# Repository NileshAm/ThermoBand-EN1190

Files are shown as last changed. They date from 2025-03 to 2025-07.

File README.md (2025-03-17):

# ThermoBand-EN1190
This is for EN1190 Design Project module. This repository contains all the design files, code and other resourse we needed to devolop the ThrmoBand Product.
## Documantation
Docimentation folder contaoin all the document in this project.
1. Proposal
2. Badget calculations
3. Survey Data.

<hr/>

<span style="font-size:1.5em;">**More details about code is in [README.md](Code/README.md) file in the Code folder**</span>
<hr/>

<span style="font-size:1.5em;">**More details about design is in [README.md](Design\README.md) file in the design folder**</span>

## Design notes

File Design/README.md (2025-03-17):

# Design
## Overview
<span style="font-size:1.2em">This contains all the design specifications and design files of the product.</span>

* Break out board must be connected in a way that **wifi chip is facing the LED**, and USB terminal is on the free end.
    * ***Note : Make sure the ```Vin``` and ```GND``` pins line up with the 2 female header pins.***
* Vin must be supplied with 5V.
* All buttons as connected to ```GND``` on free end.(Except ```D0``` button).
* As RGB LED is a commom anode LED its common terminal is connected to Vin. When power through USB or other wise LED might not turn on as Vin would not be powered.

## Circuit
### Pin out
1. **D0 (GPIO16) :**  
    * Can be connected to either push button 3 for the reset depending on the requirement.

        1.1. **Button Mode :** Put the jumper to the top position. (*Only configurable as a pull down button.*)

        1.2. **Wake Mode :** Put the jumper tot the lower position.(*Then pin is connected to RST pin and can be used to wake the ESP from deep sleep.*)

2. **D1 (GPIO5) :**  
    * Connected to the middle push button.
    * Internally pulled up (to 3.3V) by code.

3. **D2 (GPIO4) :**  
    * Connected to the **DS18B20** temperature sensor.
    * There is a 3.9 kΩ resistor to 3.3V

4. **D3 (GPIO0) :** 
    * Connected to the middle push button.
    * Internally pulled up (to 3.3V) by code.
    * **Note : *As this pin is also connected to flash pin of ESP make sure not to push while booting up.***
5. **D4 (GPIO2) :**
    * Pin of the built in LED.
    * Connecting any thing might lead to built in LED not operating as intented.
6. **3V & GND :**
    * In this board there seem that these 2 pinsare not connected or mulfunctioning.
7. **D5 (GPIO14) :**
    * Connected to the **Red** pin of the RGB LED with a 220Ω resistor.
    * As the LED is a common anode LED, pin must be set to ```LOW``` to light the LED.
8. **D6 (GPIO12) :**
    * Connected to the **Blue** pin of the RGB LED with a 220Ω resistor.
    * As the LED is a common anode LED, pin must be set to ```LOW``` to light the LED.
9. **D7 (GPIO13) :**
    * Connected to the **Green** pin of the RGB LED with a 220Ω resistor.
    * As the LED is a common anode LED, pin must be set to ```LOW``` to light the LED.
10. **D8 (GPIO15) :**
    * As its a boot critical pin avoid connecting anything to this pin.
11. **RST Pin:**
    * Depending on jumper position either connected to ```D0``` or not connected at all. Refer ```D0``` pinout for more info.

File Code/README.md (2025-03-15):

# Code

## Overview
* <code>main/src/</code> folder contains all the library and header files needed to run the program.
    * Add put header files into its over folder and then put folder in the src file to compile the library at compilation time.
    * **Note**: If files would not be compiled of put anyway else and this behaviour can lead to compilation errors.
* <code>[main.ino](main/main.ino)</code> main file which is uploaded to the ESP.

## Be Aware
1. **Do not** change the codes marked as not to edit as it could break the WIFI programming. And might need to erase the memory and reupload the code from scratch.

## Setting up WIFI Programmer on ESP
1. Reset and clear the ESP flash memory by running
<code>python -m esptool --chip esp8266 erase_flash
</code>.(**Hold down the flash button of the ESP while the command is running.**) [More Info.](https://www.youtube.com/watch?v=7ugtlgoP9Ws)

2. Upload the <code>main.ino</code> file to the ESP through Serial USB connection.
    * Note the IP address of the ESP outputed to the serial monitor.

3. Once restarted, a wifi server will be started in the name of <code>ESP8266_Config</code> connect to the wifi and go to the IP address of the earlier outputed address.

4. Enter the WIFI SSID and Password of the wifi that you what the ESP to connect to.

5. Once restarted, you will see a slow blinking LED and you will be able to access the Serial monitor by opening [WebSocketViewer.html](./main/WebSocketViewer.html). And in arduino IDE you will be able to select the ESP as a WIFI connection.
    * Note : If the ESP does not show up in ports with a wifi signal, try resetting the ESP by pressing the Rest button. And if that also does not work try restarting Arduino IDE.

## Web Serial Monitor Setup
* Open [WebSocketViewer.html](./main/WebSocketViewer.html) in a code editor and change the <code>IP</code> constant to the IP address of the ESP board.
    * Ip address of the board can be found either through your WIFI router or if you set the ESP config through the web portal IP address will be printed on the Serial Moniter when you uploaded the <code>WIFI_Programmer</code> code
* Open the [WebSocketViewer.html](./main/WebSocketViewer.html) in a web browser. After it connects to the server it will output the serial outputs.

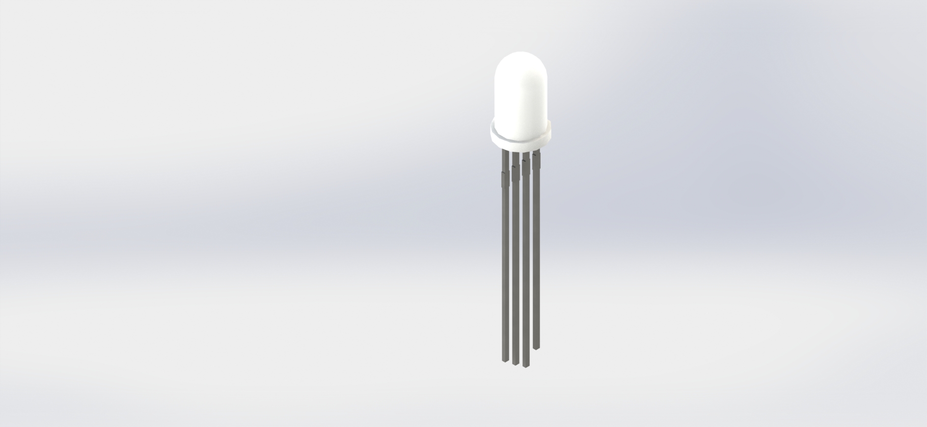
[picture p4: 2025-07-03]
Design/3D design/ca-rgb-led-5mm-1.snapshot.1/CA GRB LED 5mm.JPG

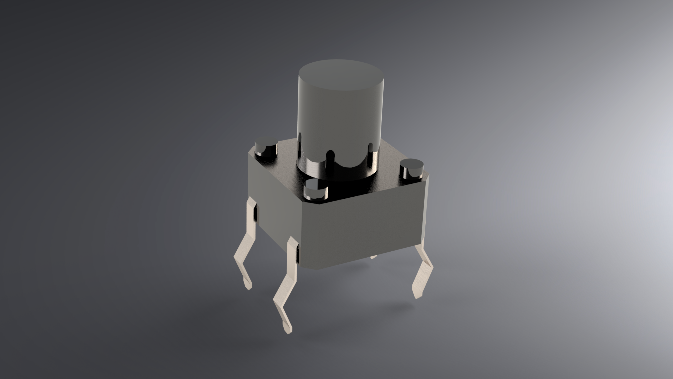
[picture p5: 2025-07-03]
Design/3D design/6x6-8mm-tach-buton_push-switch-button_mini-buton-4-arm-1.snapshot.1/Tach button.png

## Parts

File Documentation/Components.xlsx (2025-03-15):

components | price
LM35 Temperature Sensor | 360
TMP36 TMP36GT9 | 270
DS18B20 18B20 TO-92 IC CHIP Thermometer Temperature Sensor | 260

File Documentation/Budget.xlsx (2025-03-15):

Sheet: Budget
Item | price per unit | qty | total
DS18B20 IC | LKR 130.00 | 1 | LKR 130.00
LM35 IC | LKR 380.00 | 1 | LKR 380.00
RE0184 NTC Termister | LKR 30.00 | 1 | LKR 30.00
100k Potentiameter | LKR 40.00 | 1 | LKR 40.00
 |  |  | LKR 0.00
 |  |  | LKR 0.00
 |  |  | LKR 0.00
 |  |  | LKR 0.00
 |  |  | LKR 0.00
 |  |  | LKR 0.00
 |  |  | LKR 0.00
 |  |  | LKR 0.00
 |  |  | LKR 0.00
 |  |  | LKR 0.00
Total |  |  | LKR 580.00

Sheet: Contributions
person | description | amount | Person | Current contribution | Owes
Nilesh | LM35, DS18B20, RE0184 - NTC 10D-11 10ohm, 100 k pot | LKR 1060.00 | Nilesh | LKR 1060.00 | -LKR 795.00
None |  | LKR 0.00 | Tharinda | LKR 0.00 | LKR 265.00
None |  | LKR 0.00 | Chamod | LKR 0.00 | LKR 265.00
None |  | LKR 0.00 | Subodha | LKR 0.00 | LKR 265.00
None |  | LKR 0.00 | None | LKR 0.00
None |  | LKR 0.00
None |  | LKR 0.00 | Total | LKR 1060.00
None |  | LKR 0.00
None |  | LKR 0.00
None |  | LKR 0.00
None |  | LKR 0.00
None |  | LKR 0.00
None |  | LKR 0.00
None |  | LKR 0.00
None |  | LKR 0.00
None |  | LKR 0.00
None |  | LKR 0.00
None |  | LKR 0.00
None |  | LKR 0.00
None |  | LKR 0.00
None |  | LKR 0.00

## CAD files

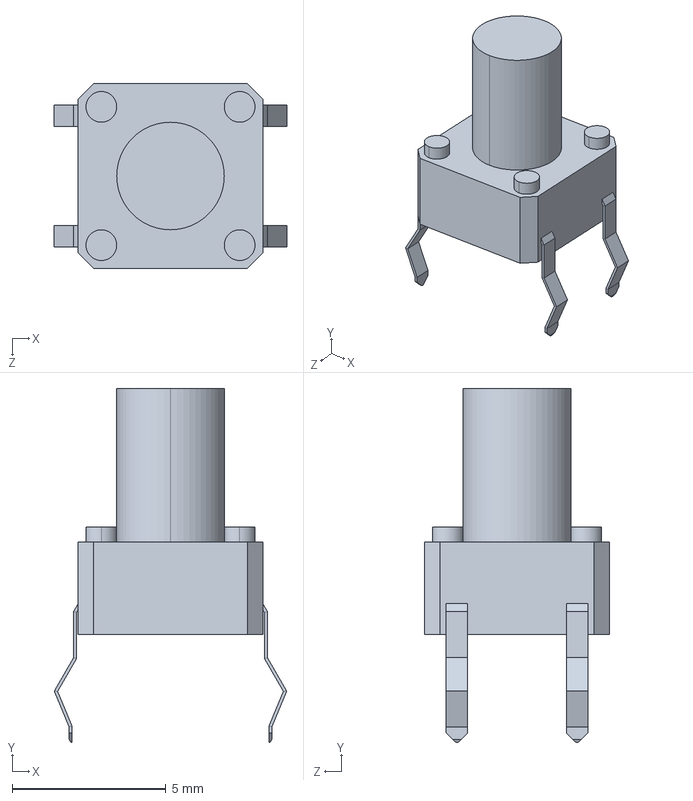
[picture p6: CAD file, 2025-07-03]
Design/3D design/6x6-8mm-tach-buton_push-switch-button_mini-buton-4-arm-1.snapshot.1/6x6 8mm Tach Buton (4 arm).STEP
7.57 x 11.5 x 6.01 mm

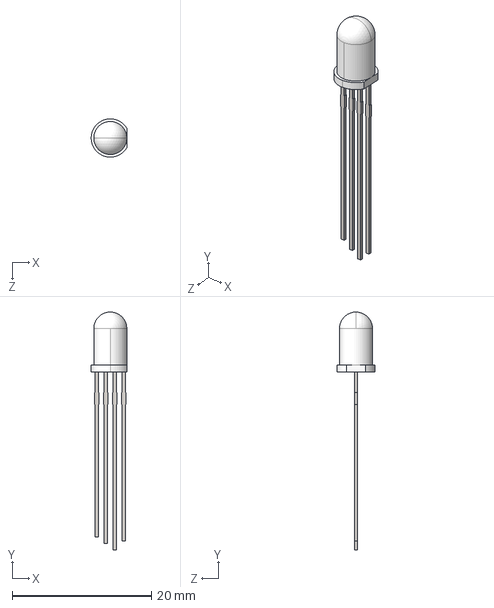
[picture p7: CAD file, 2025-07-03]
Design/3D design/ca-rgb-led-5mm-1.snapshot.1/CA GRB LED 5mm.STEP
5.12 x 34.2 x 5.50 mm

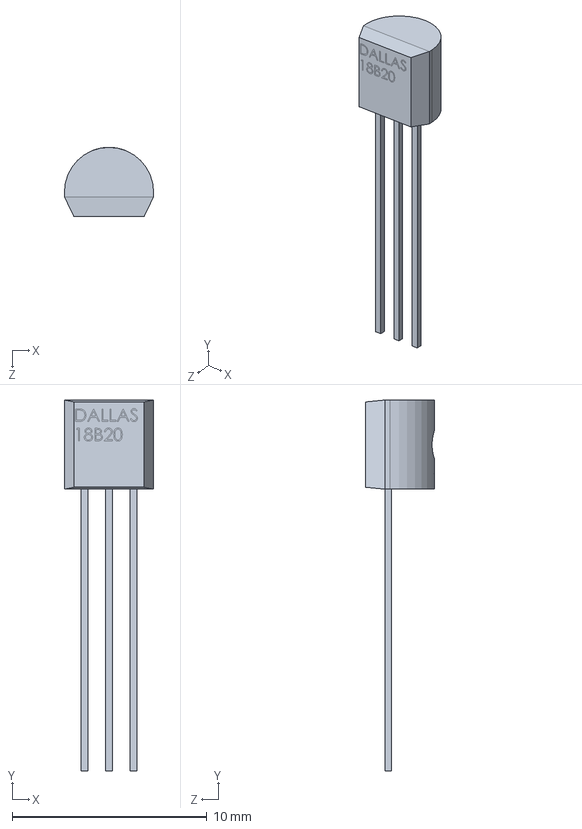
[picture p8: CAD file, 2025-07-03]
Design/3D design/DS18B20/DS18B20.SLDPRT
4.58 x 19.0 x 3.56 mm

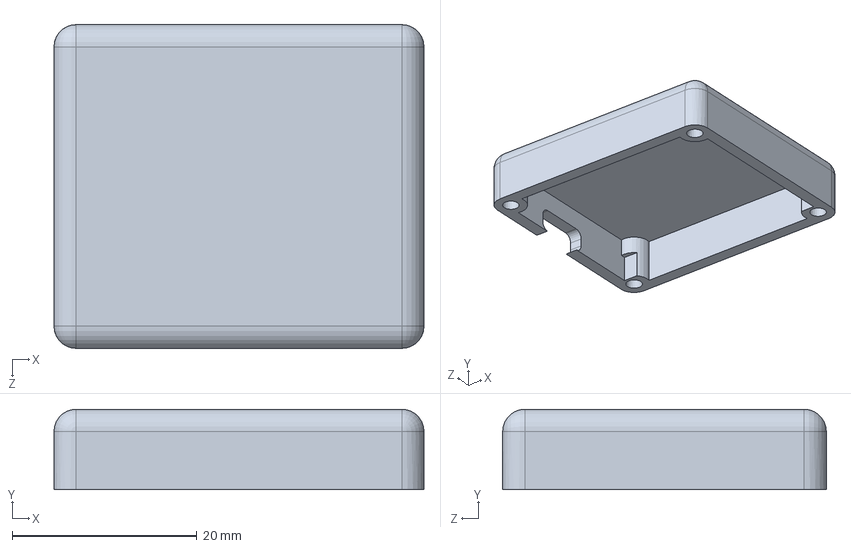
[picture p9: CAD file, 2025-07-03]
Design/3D design/Housing cover.SLDPRT
40.0 x 8.70 x 35.0 mm

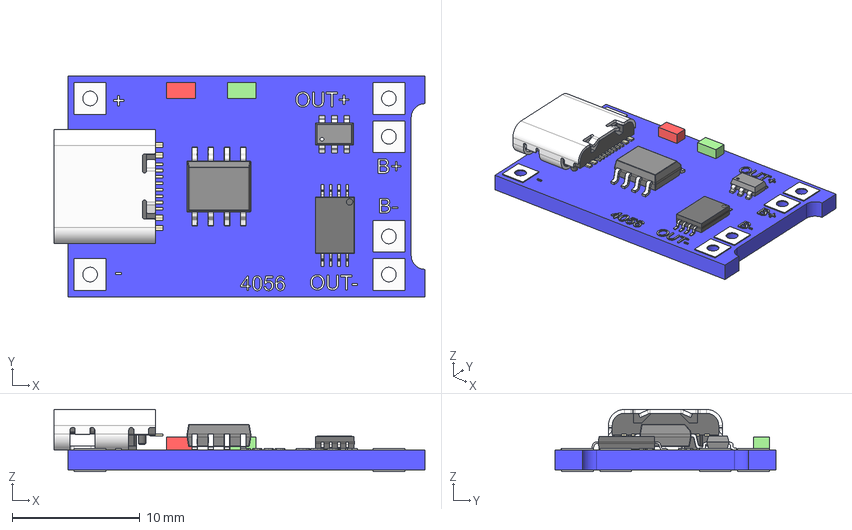
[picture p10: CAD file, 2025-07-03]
Design/3D design/tp4056-charging-module-type-c-1.snapshot.1/TP4056_Charging_Module_Type_C.step
29.1 x 17.3 x 4.86 mm
Shroud
Plastic Body & Connector
ATiny45_Body
ATiny45_Pin x 8
IC SMD 8 Pins
Pin2
Pin4
Pin6
Pin1
Pin3
Pin5

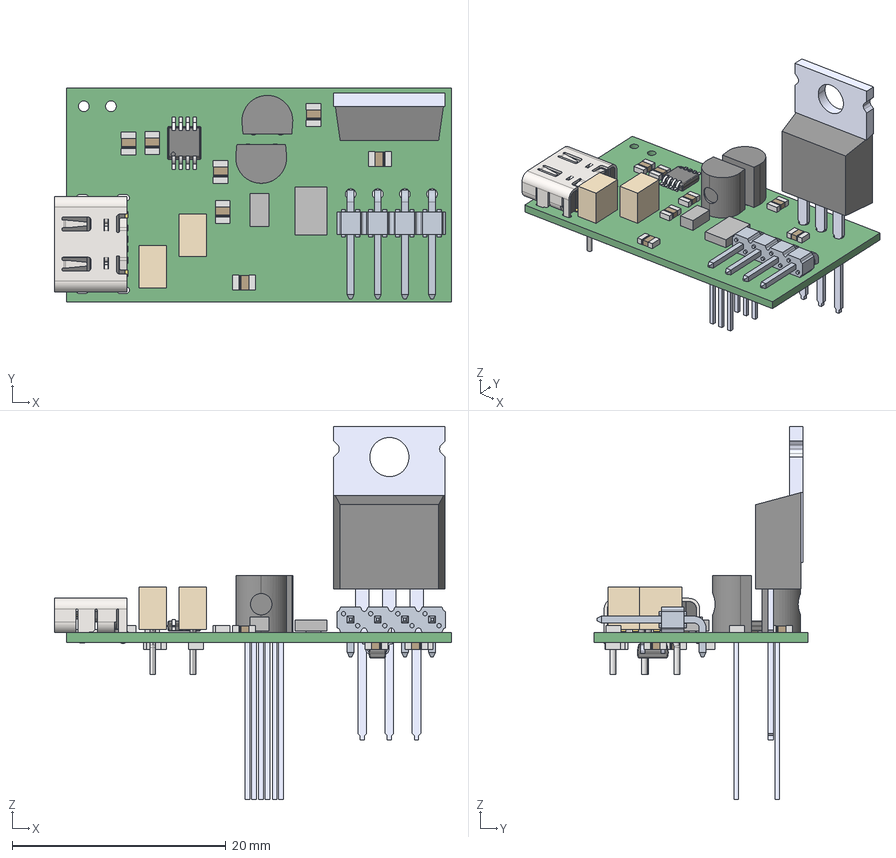
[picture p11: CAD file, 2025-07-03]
Design/Circuit Design/Power_circuit/PowerBoard.step
37.1 x 20.0 x 34.9 mm
RES_CRGCQ0805F1K2_TEC x 13
USB Connector Type C female 6pin
IRF9540N
10129379-904002BLF
KSC1008YBU_KSC1008YBU x 2
Extruded x 2
Leader x 8
K104K15X7RF5TL2_VIS x 2

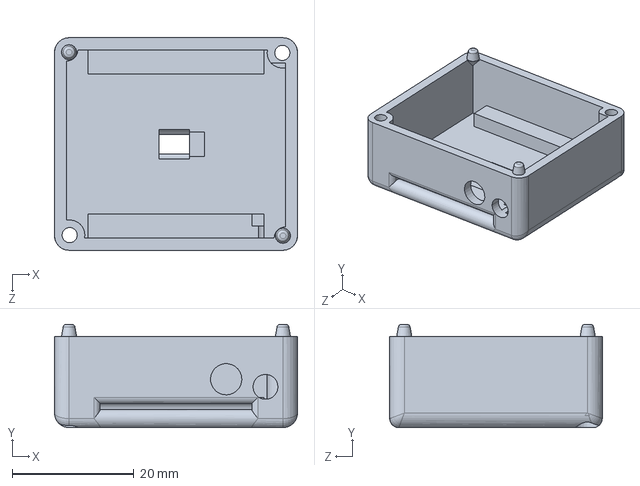
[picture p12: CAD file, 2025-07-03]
Design/3D design/Housing.SLDPRT
40.0 x 17.0 x 35.0 mm

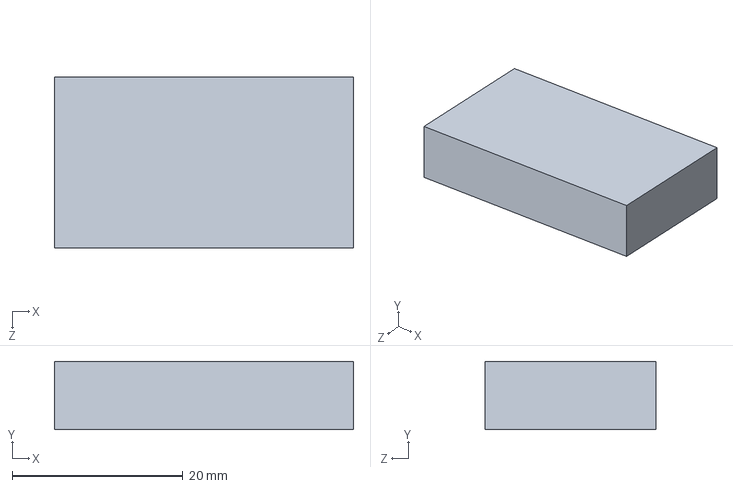
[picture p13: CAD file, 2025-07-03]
Design/3D design/Battery.SLDPRT
35.0 x 8.00 x 20.0 mm

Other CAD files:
Design/3D design/ca-rgb-led-5mm-1.snapshot.1/6x6 8mm Tach Buton (4 arm).step.SLDPRT
Design/3D design/6x6-8mm-tach-buton_push-switch-button_mini-buton-4-arm-1.snapshot.1/6x6 8mm Tach Buton (4 arm).SLDPRT
Design/3D design/Assembly.SLDDRW
Design/3D design/DS18B20/DS18B20.IGS
Design/3D design/Housing cover.STL
Design/3D design/Housing.STL
Design/3D design/ca-rgb-led-5mm-1.snapshot.1/CA GRB LED 5mm.SLDPRT
Design/3D design/tp4056-charging-module-type-c-1.snapshot.1/TP4056_Charging_Module_Type_C.SLDASM

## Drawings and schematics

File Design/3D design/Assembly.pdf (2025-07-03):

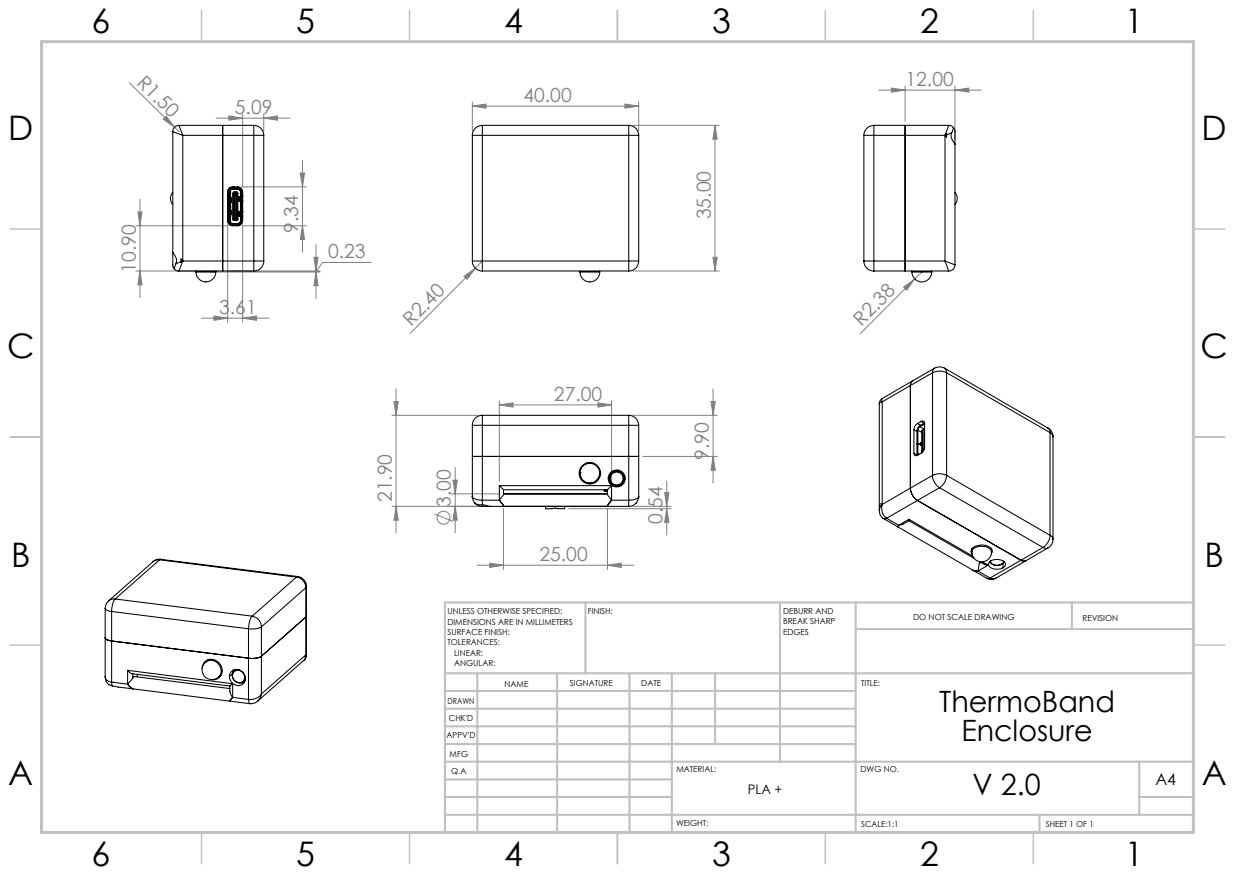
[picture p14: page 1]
FINISH:; DEBURR AND; BREAK SHARP; DO NOT SCALE DRAWING; REVISION; SCALE:1:1; SHEET 1 OF 1

UNLESS OTHERWISE SPECIFIED:
DIMENSIONS ARE IN MILLIMETERS
SURFACE FINISH:
TOLERANCES:
LINEAR:
ANGULAR:

NAME | SIGNATURE | DATE | | | | TITLE: ThermoBand Enclosure

DRAWN
CHK'D
APPV'D
MFG
Q.A | | | | MATERIAL: PLA + | DWG NO. V 2.0 | A4

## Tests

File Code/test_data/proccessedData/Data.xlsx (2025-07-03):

 | T1 |  |  |  |  | T2
 | actual | device | device with offset | device with weighted mean offset | offset error | actual | device | device with offset | device with weighted mean offset | offset error
 | 36.5 | 32.44 | 36.12071429 | 36.22520675 | -0.3792857143 | 36.3 | 31.56 | 35.51625 | 35.34520675 | -0.78375
 | 36.5 | 32.75 | 36.43071429 | 36.53520675 | -0.06928571429 | 36.5 | 31.94 | 35.89625 | 35.72520675 | -0.60375
 | 36.5 | 32 | 35.68071429 | 35.78520675 | -0.8192857143 | 36.5 | 32 | 35.95625 | 35.78520675 | -0.54375
 | 36.6 | 32.63 | 36.31071429 | 36.41520675 | -0.2892857143 | 36.3 | 32.13 | 36.08625 | 35.91520675 | -0.21375
 | 36.5 | 32.94 | 36.62071429 | 36.72520675 | 0.1207142857 | 36.2 | 31.94 | 35.89625 | 35.72520675 | -0.30375
 | 36.5 | 33.31 | 36.99071429 | 37.09520675 | 0.4907142857 | 36.4 | 31.88 | 35.83625 | 35.66520675 | -0.56375
 | 36.5 | 33.5 | 37.18071429 | 37.28520675 | 0.6807142857 | 36.5 | 32.06 | 36.01625 | 35.84520675 | -0.48375
 | 36.6 | 32.94 | 36.62071429 | 36.72520675 | 0.02071428571 | 36.5 | 32.5 | 36.45625 | 36.28520675 | -0.04375
 | 36.1 | 32.5 | 36.18071429 | 36.28520675 | 0.08071428571 | 36.6 | 32.81 | 36.76625 | 36.59520675 | 0.16625
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

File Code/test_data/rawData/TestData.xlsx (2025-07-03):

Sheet: t1
actual | device
36.5 | 32.44
36.5 | 32.75
36.5 | 32
36.6 | 32.63
36.5 | 32.94
36.5 | 33.31
36.5 | 33.5
36.6 | 32.94
36.1 | 32.5
36.4 | 32.75
36.5 | 33
36.5 | 32.88
36.1 | 32.5
36.5 | 32.63

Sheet: t2
actual | device
36.3 | 31.56
36.5 | 31.94
36.5 | 32
36.3 | 32.13
36.2 | 31.94
36.4 | 31.88
36.5 | 32.06
36.5 | 32.5
36.6 | 32.81
36.5 | 33.06
36.5 | 32.5
36.5 | 32.38
36.4 | 32.69
36.4 | 33
35.8 | 33.06
36.1 | 33.19

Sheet: t3
actual | device
36.1 | 33.88
36.2 | 34.5
36.2 | 34.31
36.3 | 34.31
36.2 | 34.31
36.2 | 34.13
36.2 | 34.25
36.4 | 34.56
36.3 | 34.63
36.1 | 34.56
36 | 34.56
36.2 | 34.44
36.2 | 34.63
36.1 | 34.56
36.1 | 34.5

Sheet: t4
actual | device
35.7 | 34.31
36.3 | 34.25
36.3 | 34.19
36.1 | 34.56
36 | 34.06
36.1 | 34.56
36.3 | 34.94
36.5 | 35.25
36.5 | 35
36.5 | 35
36.5 | 35.19
36.3 | 35.38
36.6 | 35.44
36.6 | 35.5
36.7 | 35.69
36.5 | 35.13
36.5 | 34.5
36.3 | 34.06
36.5 | 34.06
36.7 | 34.25
36.5 | 34.13
36.5 | 33.94
36.5 | 33.5
36.5 | 33.5
36.6 | 33.31
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

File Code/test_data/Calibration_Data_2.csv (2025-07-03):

actual | device
36.5 | 39.13
36.5 | 37.06
36.7 | 36.63
36.8 | 37.25
36.8 | 38.38
36.7 | 40.94
36.7 | 39.38
36.7 | 39.19
36.8 | 39.75
36 | 37.31
36.3 | 38.94
36.7 | 40.25
36.7 | 38.06
36.7 | 40.5
36.8 | 40.5
36.9 | 39.63
36.8 | 40.81
36.8 | 40.25
35.80 | 38.63
35.90 | 39.81
35.30 | 39
36.40 | 38.88
36.20 | 38.25
36.20 | 38.88
36.00 | 39.69
36.00 | 38.19
36.40 | 37.94
36.30 | 38.44
36.30 | 37.06
36.30 | 37.75
35.80 | 38.13
36.10 | 39.56
36.30 | 39.06
36.30 | 39.31
36.10 | 40.31
36.20 | 39.81
36.30 | 37.88
36.10 | 39.5
36.20 | 38.38
36.30 | 38.81
36.30 | 37.56
36.20 | 36.75
36.30 | 36.19
36.50 | 37.63
36.50 | 37.56
36.50 | 37.13
36.50 | 36.5
36.60 | 38.38
36.50 | 38.38
36.30 | 38.13
35.80 | 38.25
36.10 | 37.19
35.80 | 36.69
36.10 | 38
35.90 | 38.81
36.1 | 39.19
36.3 | 40.31
36.7 | 38.38
36.6 | 38.81
36.7 | 38.38
36.7 | 40.5
36.6 | 40.38
36.7 | 39.31
36.7 | 39.06
36.8 | 38.94
36.7 | 37.69
36.5 | 39.38
36.6 | 39.31
36.7 | 39.44
36.7 | 39.13
36.7 | 39.13
36.7 | 39.69
36.9 | 38.63
36.9 | 40
36.8 | 40.13
36.9 | 38.44
36.8 | 39.94
36.7 | 39.44
36.8 | 38.06
36 | 36.44
36.4 | 38.94
36.4 | 39.5
36.6 | 38.31
36.7 | 39.63
36.6 | 38.94
36.7 | 38.94
36.7 | 40.44
36.7 | 39.06

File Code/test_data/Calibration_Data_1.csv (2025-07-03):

actual | device
36.2 | 31.5
36.3 | 31.13
35.8 | 31.06
36.3 | 31.13
36.4 | 31.19
36.5 | 31.25
36.5 | 31.5
36.5 | 31.94
36 | 32.19
36.3 | 32.5
36.4 | 32.5
36.4 | 32.19
36.4 | 32.5
36.4 | 32.63
35.6 | 33
36.6 | 33.13
36.6 | 33.31
36.5 | 33.38
36.5 | 33.38
36.6 | 33.5
36.5 | 33.38
36.5 | 33.31
36.7 | 32.63
36.6 | 32.81
36.7 | 32.81
36.7 | 32.38
36.7 | 32.06
36.7 | 31.75
36.5 | 31.63
36.6 | 31.31
36.3 | 31.25
36.4 | 31.44
36.5 | 31.44
36.5 | 31.25
36.7 | 31.06
36.6 | 30.81
36.1 | 30.38
36.4 | 31.38
36.3 | 31.38
36.5 | 31.88
36.4 | 32.06
36.8 | 32
36.6 | 31.56
36.7 | 31.56
36.8 | 31.44
36.7 | 30.94
36.7 | 31
36.7 | 30.88
36.4 | 30.81
36.4 | 30.94
36.3 | 31.19
36.6 | 31.25
36.5 | 31.38
36.4 | 31.38
36.7 | 31.25
36.5 | 31.06
36.5 | 31.06
36.7 | 31.25
36.8 | 31.25
36.8 | 31.19
36.7 | 30.88
36.7 | 31.25
36.7 | 31.38
36.8 | 31.69
36 | 31.75
36.3 | 31.69
36.7 | 31.69
36.7 | 31.56
36.7 | 31.44
36.8 | 31.25
36.9 | 31.25
36.8 | 31.19
36.8 | 31.31
35.80 | 30.69
35.90 | 30.88
35.30 | 30.88
36.40 | 30.75
36.20 | 30.56
36.20 | 30.5
36.00 | 30.56
36.00 | 30.5
36.40 | 30.44
36.30 | 30.44
36.30 | 30.25
36.30 | 30.19
35.80 | 29.63
36.10 | 29.44
36.30 | 29.44
36.30 | 29.31
36.10 | 29.38
36.20 | 29.56

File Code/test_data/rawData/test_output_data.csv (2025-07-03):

2025-03-18T10:32:34.711879
2025-03-18T10:37:19.283346 | 32.44
2025-03-18T10:42:19.973228 | 32.75
2025-03-18T10:47:20.995647 | 32.00
2025-03-18T10:52:21.351862 | 32.63
2025-03-18T10:57:22.042917 | 32.94
2025-03-18T11:02:22.727562 | 33.31
2025-03-18T11:07:23.416370 | 33.50
2025-03-18T11:12:24.107364 | 32.94
2025-03-18T11:17:24.797277 | 32.50
2025-03-18T11:22:25.486934 | 32.75
2025-03-18T11:27:26.178464 | 33.00
2025-03-18T11:37:27.550462 | 32.88
2025-03-18T11:42:28.242636 | 32.50
2025-03-18T11:47:28.929869 | 32.63

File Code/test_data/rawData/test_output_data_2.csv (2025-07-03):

2025-04-04T11:55:21.942091
2025-04-04T11:55:27.602986 | 33.25

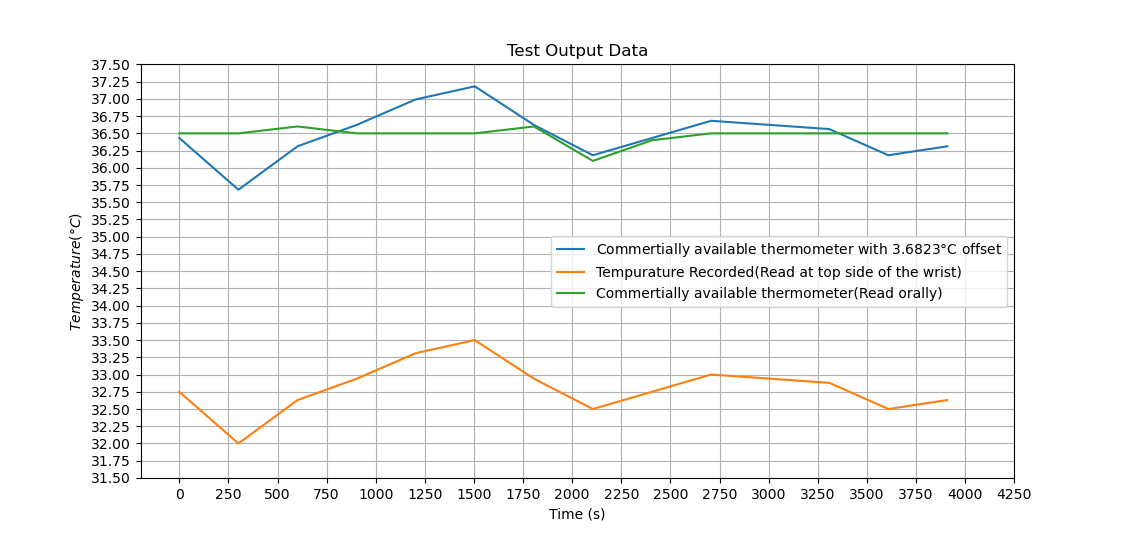
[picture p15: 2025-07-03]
Code/test_data/rawData/test_data_plot.png

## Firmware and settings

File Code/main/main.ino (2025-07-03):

// ######################### Do not change this Code ###########################################
#include "src/WIFI_Programmer.h"
#include "src/SerialWebLogger.h"
// #############################################################################################
#include "src/DigitalTempSensor.h"
#include "src/Blinker.h"
#include "src/Button.h"
#include "src/HTTPRequest.h"

#include <EEPROM.h>
#include <ArduinoJson.h>
#include <pgmspace.h>

/* ------------------- EEPROM layout & constants ------------------- */
#define MAX_SSID_LEN    100
#define MAX_PASS_LEN    100
#define MAX_UID_LEN     37
#define MAX_MAC_LEN     18

#define EEPROM_SSID_ADDR       0
#define EEPROM_PASS_ADDR      (EEPROM_SSID_ADDR + MAX_SSID_LEN)
#define EEPROM_UID_ADDR       (EEPROM_PASS_ADDR + MAX_PASS_LEN)
#define EEPROM_MAC_ADDR       (EEPROM_UID_ADDR + MAX_UID_LEN)
#define EEPROM_INTERVAL_ADDR  (EEPROM_MAC_ADDR + MAX_MAC_LEN)
#define EEPROM_SIZE           (EEPROM_INTERVAL_ADDR + 4)


/* defaults */
#define HARD_SSID     "YourSSID"
#define HARD_PASS     "YourPassword"
#define HARD_UID      "YourUID"
#define HARD_INTERVAL 300          // 5mins in seconds

/* server */
#define SERVER_URL    "https://thermoband-production.up.railway.app"

/* ------------------- global state ------------------- */
String storedMAC;                    // filled in setup
int    INTERVAL = HARD_INTERVAL;                 // will be updated from server

// Blinker blinker(14);
Button  btn1(5, 100);               // long‑press reset
Button  btn2(0, 50);

StaticJsonDocument<256> jdoc;        // reused buffer

/* ------------------- utility ------------------- */
inline void eepromWriteIfDiff(int addr, char value)
{
  if (EEPROM.read(addr) != value) EEPROM.write(addr, value);
}

static bool waitWiFi(uint8_t retries = 20, uint16_t stepMs = 500)
{
  while (WiFi.status() != WL_CONNECTED && retries--) {
    delay(stepMs);
  }
  return WiFi.status() == WL_CONNECTED;
}

static void factoryReset()
{
  for (int i = 0; i < MAX_SSID_LEN;  ++i) eepromWriteIfDiff(EEPROM_SSID_ADDR + i, HARD_SSID[i]);
  for (int i = 0; i < MAX_PASS_LEN;  ++i) eepromWriteIfDiff(EEPROM_PASS_ADDR + i, HARD_PASS[i]);
  EEPROM.commit();
  ESP.restart();
}

float poly_func(float x) {
    // Coefficients for order 4 polynomial
    float c[] = {-0.0013469376, 0.2189753045, -13.2929114574, 357.3340705466, -3554.4054571583};
    float value = 0;
    for (int i = 0; i < 5; i++) {
        value += c[i] * pow(x, 4 - i);
    }
    return value;
}

/* ------------------- setup ------------------- */
void setup()
{ 

  pinMode(12, OUTPUT);   // green  LED
  pinMode(13, OUTPUT);   // blue   LED
  pinMode(14, OUTPUT);   // red   LED
  
  digitalWrite(12, LOW);                    
  digitalWrite(13, HIGH);                     
  digitalWrite(14, HIGH);

  // blinker.setupBlinker();

  // ######################### Do not change this Code ###########################################
  Serial.begin(115200);
  wifiSetupOTA();
  initSerialWebLogger();
  // #############################################################################################
  btn1.begin();
  btn2.begin();

  EEPROM.begin(EEPROM_SIZE);

  setupSensor(4);
  tempSensorBegin();
  setResolution(12);

  setupHTTP(F(SERVER_URL));

  /* build storedMAC from EEPROM */
  storedMAC.reserve(MAX_MAC_LEN);
  for (int i = 0; i < MAX_MAC_LEN; ++i) {
    char c = EEPROM.read(EEPROM_MAC_ADDR + i);
    if (c == '\0' || c == (char)0xFF) break;
    storedMAC += c;
  }


  /* quick server self‑test */
  String res = HTTPGET(F("/"));
  deserializeJson(jdoc, res);
  if (jdoc["message"] != "Health Monitoring Backend API is running") {
    digitalWrite(13, LOW);                     
  } else if (jdoc.containsKey("interval")) {
    int eepInterval;
    EEPROM.get(EEPROM_INTERVAL_ADDR, eepInterval);
    if (eepInterval != jdoc["interval"].as<int>()) {
      EEPROM.put(EEPROM_INTERVAL_ADDR, jdoc["interval"].as<int>());
      EEPROM.commit();
    }
    INTERVAL = jdoc["interval"].as<int>();
  }
  delay(2000);
}

/* ------------------- loop ------------------- */
bool programMode = false;
void loop()
{
  btn1.update();
  btn2.update();
  // ######################### Do not change this Code ###########################################
  otaHandle();
  updateSerialWebLogger();
  // #############################################################################################


  
  // Serial.println("Button state");
  // delay(200);
  Serial.println(btn2.isLongPressed());
  if(btn2.isLongPressed() && !programMode){
    digitalWrite(14, LOW);
    digitalWrite(12, HIGH);
    programMode = !programMode;
  }
  if(!programMode){
    /* timed POST */

    StaticJsonDocument<96> doc;
    doc["temperature"] = poly_func(readTempSensor());
    doc["macAddress"] = storedMAC;

    String body;
    serializeJson(doc, body);

    String endpoint = F("/esp32/add-temperature");

    /* retry up to 3 */
    bool success = false;
    Serial.print("Sending Post request");
    while (!success) {
      Serial.print(".");
      String reply = HTTPPOST(endpoint, body);
      if (!deserializeJson(jdoc, reply) && jdoc["message"] == "Temperature recorded"){
        float t = jdoc["tempRecord"]["out_temperature"].as<float>();
        Serial.println(t);
        success = true;
      }else{
        digitalWrite(14, LOW);                   // green off = error
      }
    }
    Serial.println("#");
    digitalWrite(14, HIGH);                   // green off = error

    if (jdoc.containsKey("interval")) {
      INTERVAL = jdoc["interval"].as<int>();
      EEPROM.put(EEPROM_INTERVAL_ADDR, INTERVAL);
      EEPROM.commit();
    }
    Serial.println(jdoc.containsKey("reset"));
    Serial.println(jdoc["reset"].as<bool>());
    if (jdoc.containsKey("reset") && jdoc["reset"].as<bool>()) {
      factoryReset();
    }

    /* update Wi‑Fi creds if sent */
    if (jdoc.containsKey("SSID")) {
      String newSSID   = jdoc["SSID"    ];
      String newPass   = jdoc["Password"];
      for (int i = 0; i < MAX_SSID_LEN; ++i) eepromWriteIfDiff(EEPROM_SSID_ADDR + i, newSSID[i]);
      for (int i = 0; i < MAX_PASS_LEN; ++i) eepromWriteIfDiff(EEPROM_PASS_ADDR + i, newPass[i]);
      EEPROM.commit();
      ESP.restart();
    }

    digitalWrite(12, HIGH);
    // blinker.blink(1000);
    Serial.println("sleep");
    ESP.deepSleep(INTERVAL*1000000);
  }
}

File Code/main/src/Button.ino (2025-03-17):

#include "Button.h"

Button myButton(5, 2000);

void setup() {
  myButton.begin();
}

void loop() {
  myButton.update();

  // Check for event-based press detection.
  if (myButton.wasShortPress()) {
    logMessage("Short press event detected");
  }
  if (myButton.wasLongPress()) {
    logMessage("Long press event detected");
  }
  
  // For continuous state detection, check if the button is currently pressed.
  if (myButton.isShortPressed()) {
    logMessage("Button is currently pressed (short)");
  }
  if (myButton.isLongPressed()) {
    logMessage("Button is currently pressed (long)");
  }

}

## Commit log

2025-03-15 File structure setup.
    [Budget.xlsx, Components.xlsx]
2025-03-17 Button header file made
2025-03-20 3D design initial commit
    [6x6 8mm Tach Buton (4 arm).SLDPRT, 6x6 8mm Tach Buton (4 arm).STEP, 6x6 8mm Tach Buton (4 arm).step.SLDPRT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]
2025-04-04 test push
    [Data.xlsx, TestData.xlsx, test_output_data.csv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]
2025-04-12 Add modified and new test data files
    [TestData.xlsx, test_output_data_3.csv, test_output_data_4.csv]
2025-04-24 Reset added Initialization page modified
    [PowerBoard.step]
2025-05-05 PCB design of sensor and power board finalize
    [ESP FinalLast.PrjPcb, Power.PrjPcb, Power.SchDoc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]
2025-05-07 3d Design finalized.
    [Assembly.SLDDRW, DS18B20.SLDPRT, Housing cover.SLDPRT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]
2025-07-02 FInal fixes on main.ino and Wifi_programmer
    [Housing cover.SLDPRT, Housing cover.STL, Housing.SLDPRT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]
2025-07-02 Calibration file made
2025-07-03 2 datasets for 2 devices made, Calibration scripts made
    [Calibration_Data_1.csv, Calibration_Data_2.csv]
2025-07-03 Device 1 calibration finished
    [Calibration_Data_1.csv]
2025-07-03 Device 2 finalized
    [Calibration_Data_2.csv]
2025-07-04 Assembly.glb file added to /public
